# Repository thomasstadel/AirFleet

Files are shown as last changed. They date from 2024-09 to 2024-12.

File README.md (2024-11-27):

# AirFleet
Mobil kortlægning af luftkvalitet

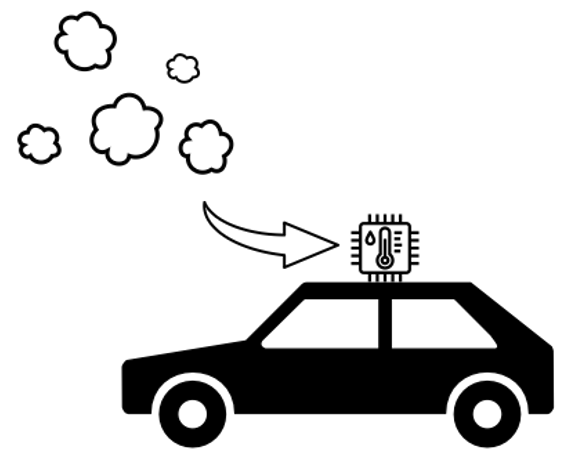
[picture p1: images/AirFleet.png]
AirFleet


## Formål
Formålet med dette projekt er at udvikle en IoT-løsning, der kan indsamle samples af luftkvalitet, herunder partikler, fugtighed, temperatur, CO2 baseret på GPS-lokation.

Enheden skal kunne installeres udvendigt (evt. ved luftindtag) på en bil.

Indsamlede data skal leveres til en webservice, hvor de skal gemmes i en database til efterfølgende analyse.

Der skal være et display på IoT-enheden, som giver mulighed for at informere føreren af bilen om luftkvalitet. 

Optimalt set vil IoT-enheden automatisk aktivere recirkulation i bilen ved lav luftkvalitet.

## Mappe-struktur

schematics/     Diagrammer og PCB layouts

display/        Kode relateret til display board

sensor/         Kode relateret til sensor board

stl/            STL-modeller af bokse

webserver/      Kode og database til webserver

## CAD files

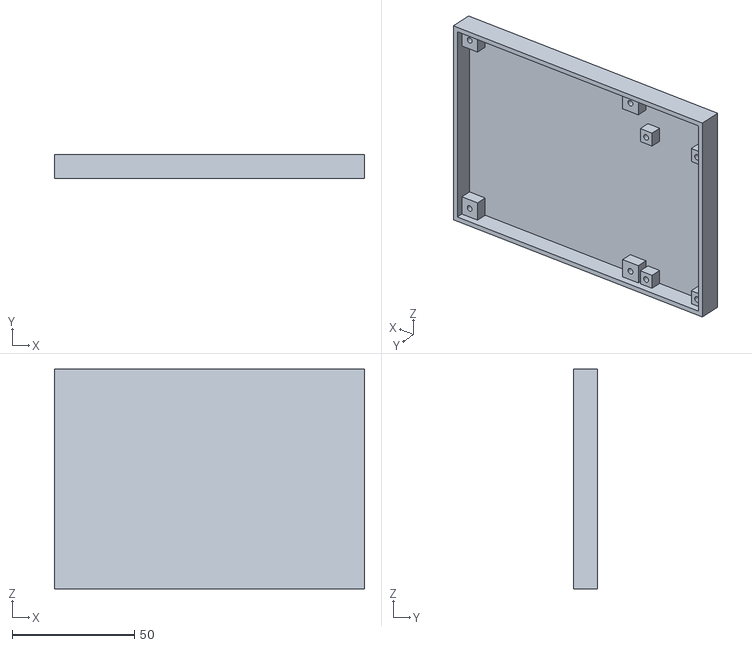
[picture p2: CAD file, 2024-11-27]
stl/sensor_bottom.stl
127.0 x 10.0 x 90.0

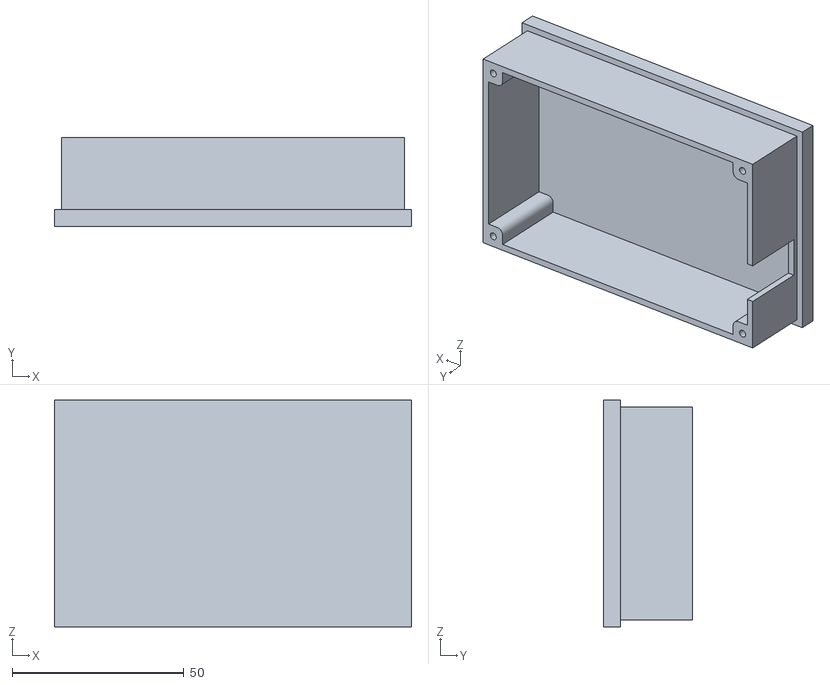
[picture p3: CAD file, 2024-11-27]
stl/display_back.stl
104.0 x 26.0 x 66.0

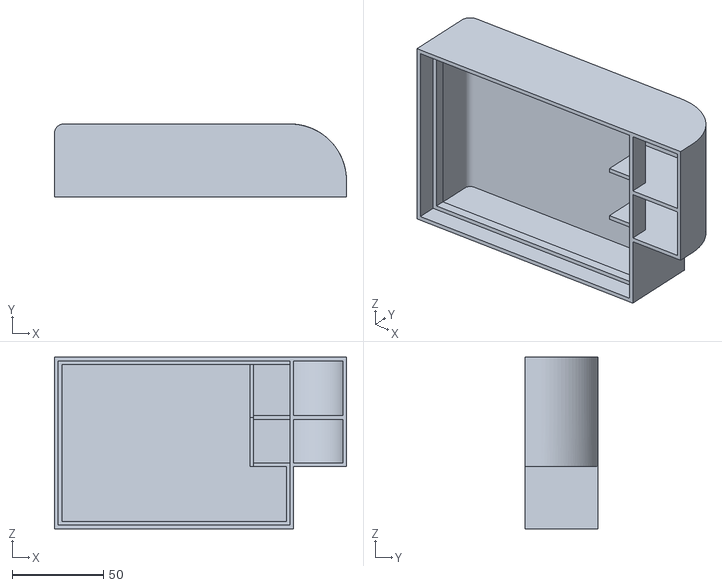
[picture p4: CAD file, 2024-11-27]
stl/sensor_top.stl
160.0 x 40.0 x 94.0

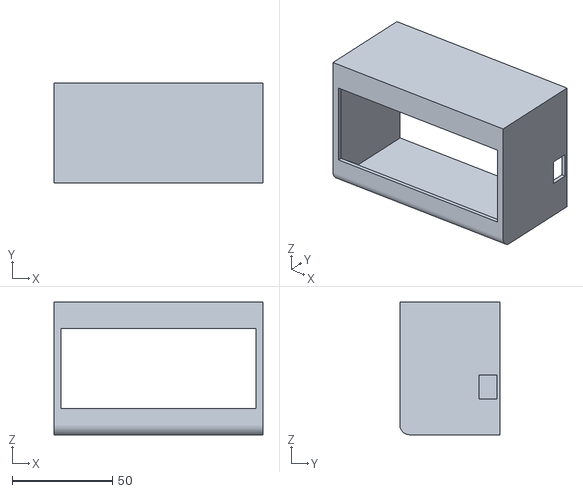
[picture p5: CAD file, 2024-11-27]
stl/display_front.stl
104.0 x 50.0 x 66.0

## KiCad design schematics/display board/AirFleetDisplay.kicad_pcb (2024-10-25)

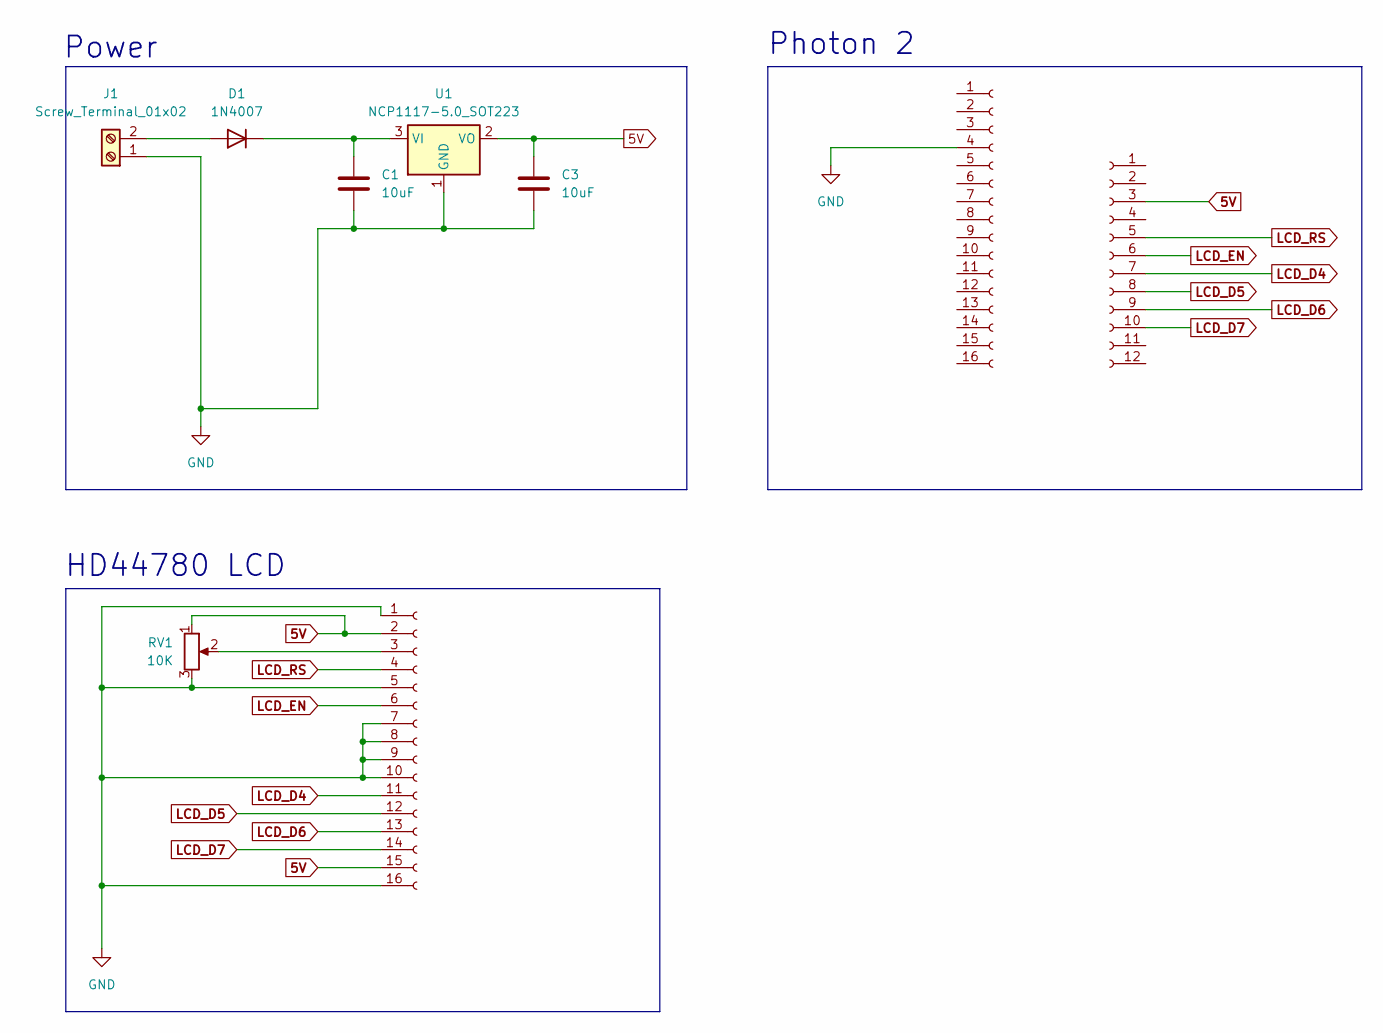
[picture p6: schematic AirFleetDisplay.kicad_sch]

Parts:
C1, C3: 10uF; C_1210_3225Metric_Pad1.33x2.70mm_HandSolder
D1: 1N4007; D_DO-15_P15.24mm_Horizontal
J1: Screw_Terminal_01x02; TerminalBlock_bornier-2_P5.08mm
J2, J4: Conn_01x16_Socket; PinSocket_1x16_P2.54mm_Vertical
J3: Conn_01x12_Socket; PinSocket_1x12_P2.54mm_Vertical
RV1: 10K; Potentiometer_Bourns_3386P_Vertical
U1: NCP1117-5.0_SOT223; SOT-223-3_TabPin2

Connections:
5V: C3.1, J3.3, J4.2, J4.15, RV1.1, U1.2 (VO)
GND: C1.2, C3.2, J1.1, J2.4, J4.1, J4.5, J4.7, J4.8, J4.9, J4.10, J4.16, RV1.3, U1.1 (GND)
LCD_D4: J3.7, J4.11
LCD_D5: J3.8, J4.12
LCD_D6: J3.9, J4.13
LCD_D7: J3.10, J4.14
LCD_EN: J3.6, J4.6
LCD_RS: J3.5, J4.4
unnamed: D1.2 (A), J1.2
unnamed: C1.1, D1.1 (K), U1.3 (VI)
unnamed: J4.3, RV1.2

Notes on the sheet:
HD44780 LCD
Photon 2
Power

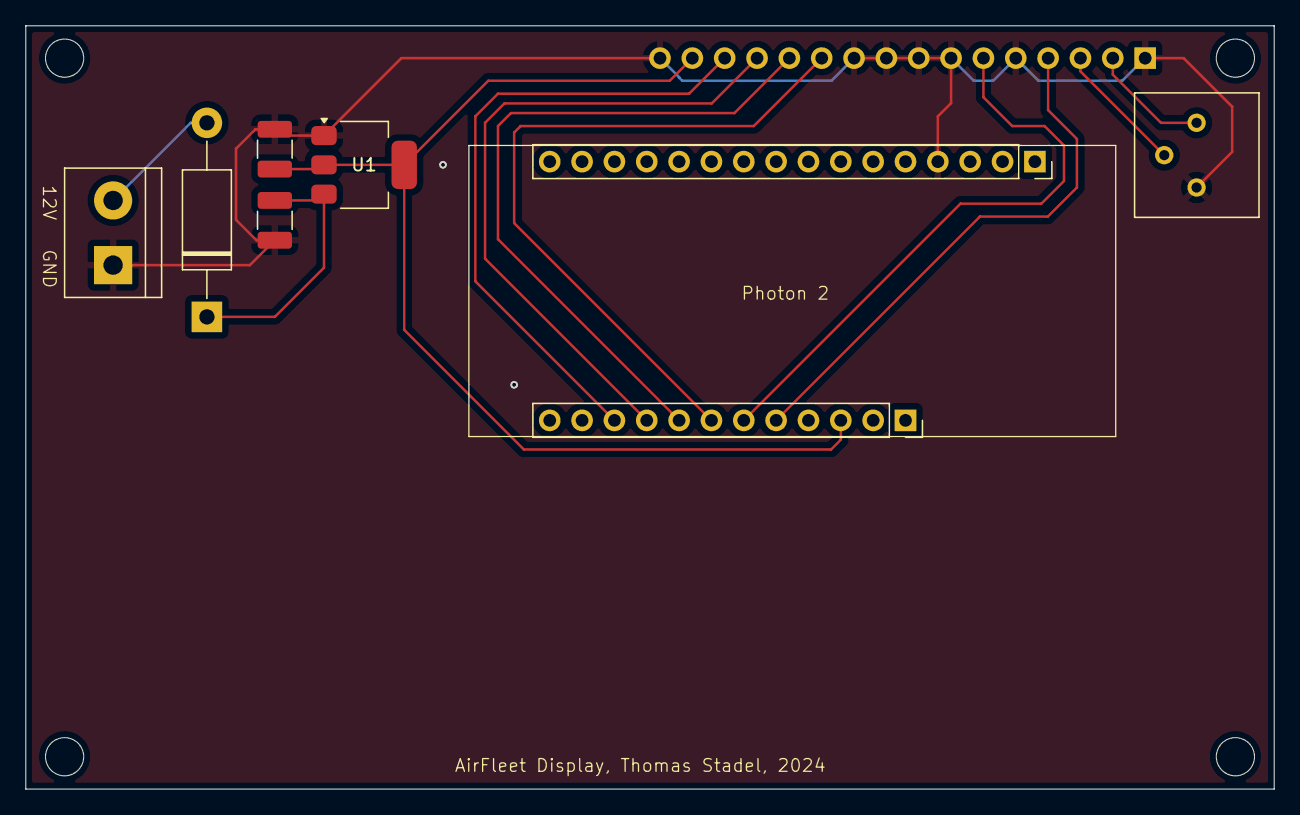
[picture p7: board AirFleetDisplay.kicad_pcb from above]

Board: 2 copper layers, 98.0 x 59.9 mm, 9 parts (1 on the bottom side), 11 nets.

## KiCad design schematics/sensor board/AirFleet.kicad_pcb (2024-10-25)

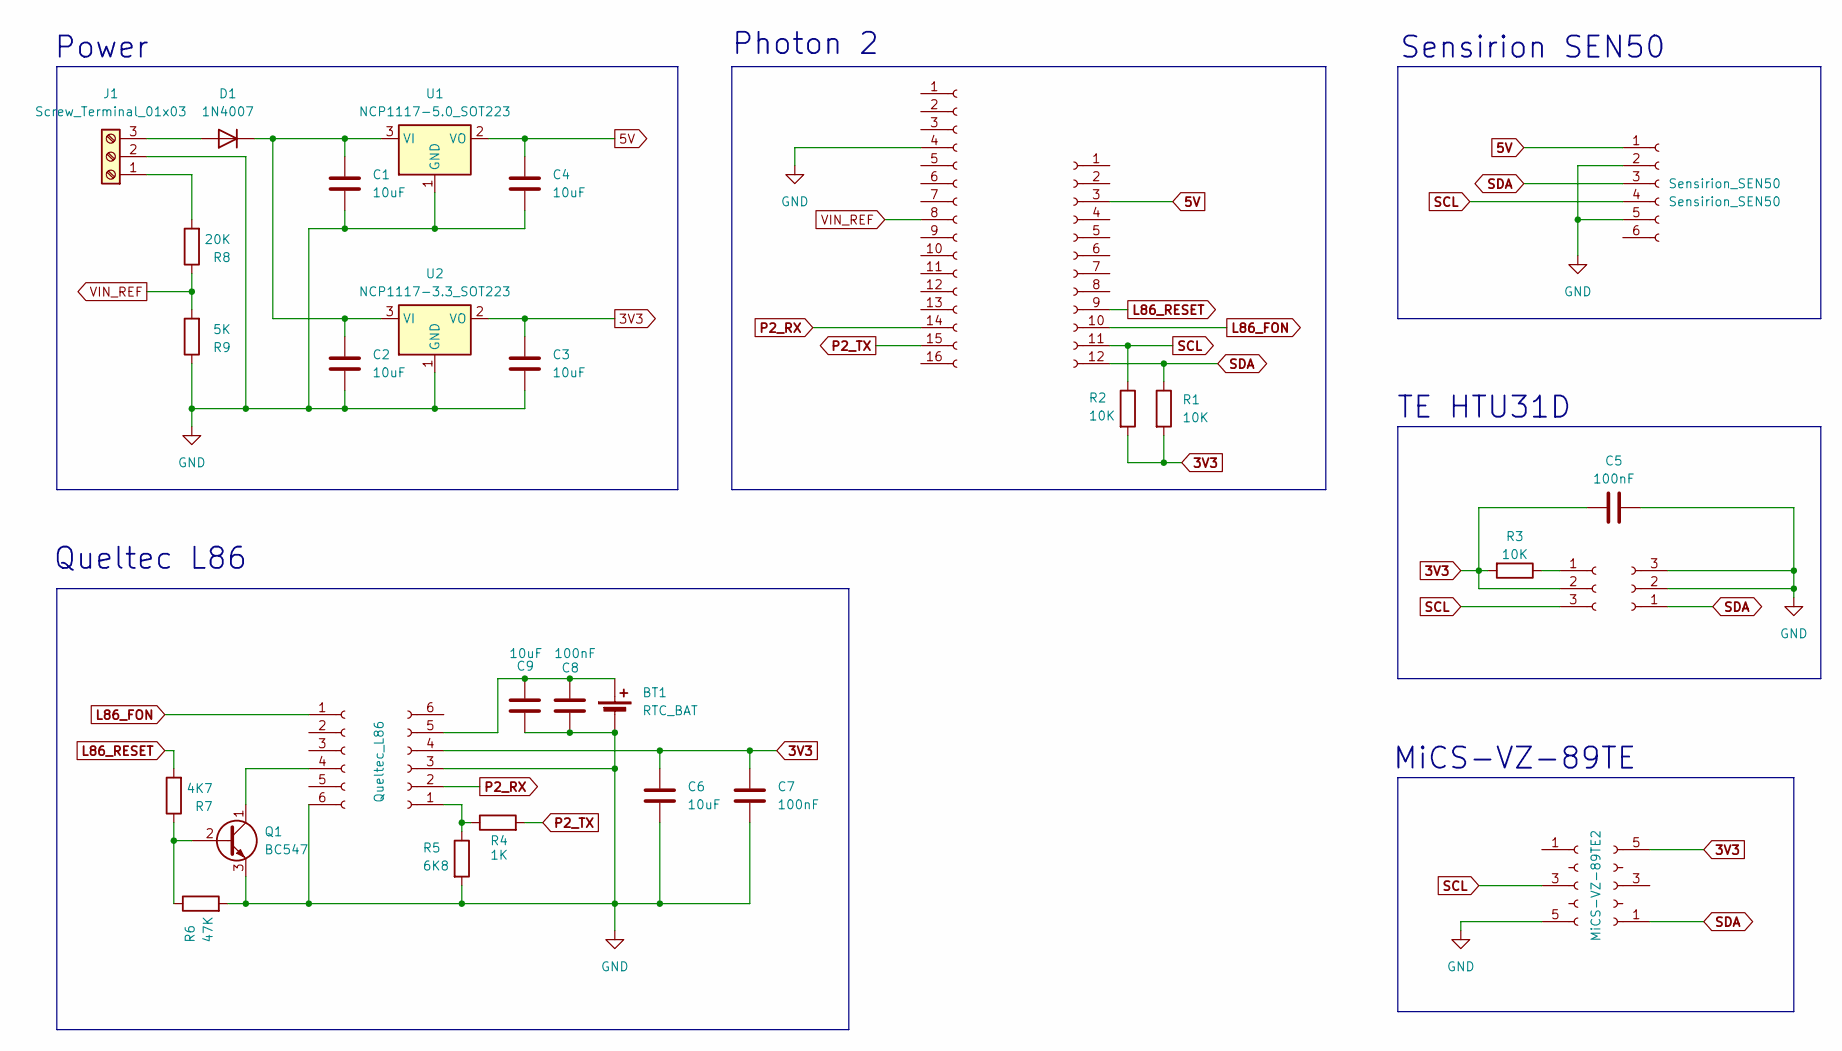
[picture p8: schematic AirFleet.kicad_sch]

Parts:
BT1: RTC_BAT; Battery_Panasonic_CR2032-HFN_Horizontal_CircularHoles
C1, C2, C3, C4, C6, C9: 10uF; C_1210_3225Metric_Pad1.33x2.70mm_HandSolder
C5, C7, C8: 100nF; C_1210_3225Metric_Pad1.33x2.70mm_HandSolder
D1: 1N4007; D_DO-15_P15.24mm_Horizontal
HTU31D1, HTU31D2: Conn_01x03_Socket; PinSocket_1x03_P2.54mm_Vertical
J1: Screw_Terminal_01x03; TerminalBlock_bornier-3_P5.08mm
J2: Conn_01x12_Socket; PinSocket_1x12_P2.54mm_Vertical
J3: Conn_01x16_Socket; PinSocket_1x16_P2.54mm_Vertical
J5: Conn_01x06_Socket; PinSocket_1x06_P2.54mm_Vertical
MiCS-VZ-89TE1, MiCS-VZ-89TE2: Conn_01x05_Socket; PinSocket_1x05_P2.54mm_Vertical
Q1: BC547; TO-92_Inline
Queltec_L86: Queltec_L86; PinSocket_1x06_P2.54mm_Vertical
R1, R2, R3: 10K; R_Axial_DIN0309_L9.0mm_D3.2mm_P12.70mm_Horizontal
R4: 1K; R_Axial_DIN0309_L9.0mm_D3.2mm_P12.70mm_Horizontal
R5: 6K8; R_Axial_DIN0309_L9.0mm_D3.2mm_P12.70mm_Horizontal
R6: 47K; R_Axial_DIN0309_L9.0mm_D3.2mm_P12.70mm_Horizontal
R7: 4K7; R_Axial_DIN0309_L9.0mm_D3.2mm_P12.70mm_Horizontal
R8: 20K; R_Axial_DIN0309_L9.0mm_D3.2mm_P12.70mm_Horizontal
R9: 5K; R_Axial_DIN0309_L9.0mm_D3.2mm_P12.70mm_Horizontal
Sensirion_SEN50: Sensirion_SEN50; PinSocket_1x06_P2.54mm_Vertical
U1: NCP1117-5.0_SOT223; SOT-223-3_TabPin2
U2: NCP1117-3.3_SOT223; SOT-223-3_TabPin2

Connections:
3V3: C3.1, C5.1, C6.1, C7.1, HTU31D1.2, MiCS-VZ-89TE2.5, Queltec_L86.4, R1.2, R2.2, R3.2, U2.2 (VO)
5V: C4.1, J2.3, Sensirion_SEN50.1, U1.2 (VO)
GND: BT1.2 (-), C1.2, C2.2, C3.2, C4.2, C5.2, C6.2, C7.2, C8.2, C9.2, HTU31D2.2, HTU31D2.3, J1.2, J3.4, J5.6, MiCS-VZ-89TE1.5, Q1.3 (E), Queltec_L86.3, R5.2, R6.2, R9.1, Sensirion_SEN50.2, Sensirion_SEN50.5, U1.1 (GND), U2.1 (GND)
L86_FON: J2.10, J5.1
L86_RESET: J2.9, R7.2
unnamed: BT1.1 (+), C8.1, C9.1, Queltec_L86.5
unnamed: D1.2 (A), J1.3
unnamed: C1.1, C2.1, D1.1 (K), U1.3 (VI), U2.3 (VI)
unnamed: HTU31D1.1, R3.1
unnamed: J1.1, R8.2
unnamed: J5.4, Q1.1 (C)
unnamed: Q1.2 (B), R6.1, R7.1
unnamed: Queltec_L86.1, R4.1, R5.1
P2_RX: J3.14, Queltec_L86.2
P2_TX: J3.15, R4.2
SCL: HTU31D1.3, J2.11, MiCS-VZ-89TE1.3, R2.1, Sensirion_SEN50.4
SDA: HTU31D2.1, J2.12, MiCS-VZ-89TE2.1, R1.1, Sensirion_SEN50.3
VIN_REF: J3.8, R8.1, R9.2

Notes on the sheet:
Sensirion SEN50
Queltec L86
TE HTU31D
MiCS-VZ-89TE
Photon 2
Power

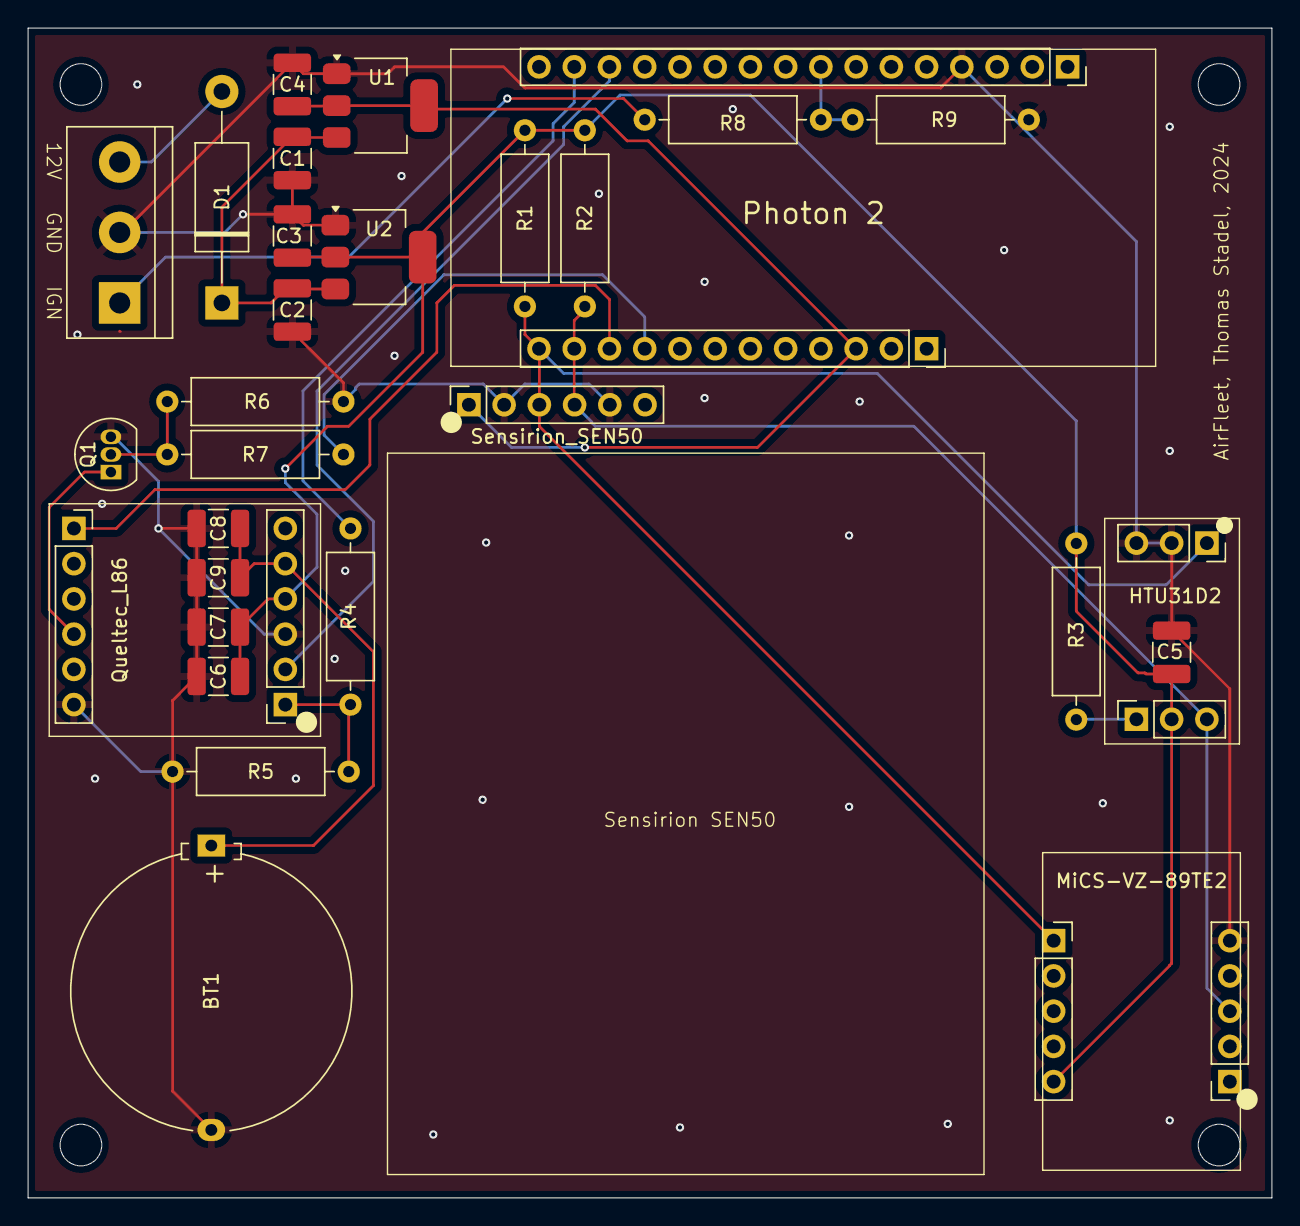
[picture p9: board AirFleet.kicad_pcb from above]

Board: 2 copper layers, 89.7 x 84.3 mm, 33 parts (0 on the bottom side), 18 nets.

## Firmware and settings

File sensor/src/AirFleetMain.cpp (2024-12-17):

/*
	@author:  Thomas Stadel
	@date:    2024-12-15
	@brief:   AirFleet mobile air quality sensor
*/

#include "Particle.h"

#include "BleLcd.h"
#include "Sen50.h"
#include "Htu31.h"
#include "Mics.h"
#include "L86.h"

#include "Settings.h"

// Run manual mode so we can control WiFi etc.
SYSTEM_MODE(MANUAL);

// Run the application and system concurrently in separate threads
SYSTEM_THREAD(ENABLED);

// Log handler (can be disabled in Settings.h)
#ifdef AIRFLEET_DEBUG
SerialLogHandler logHandler(LOG_LEVEL_INFO);
#endif

// BLE LCD
BleLcd lcd;

// Sensirion SEN50: particle sensor - has absolutely nothing to do with particle.io :-P
Sen50 sen50;

// HTU31 sensor: temperature + humidity
Htu31 htu31;

// MiCS sensor: VOC+CO2
Mics mics;

// L86 GPS module
L86 l86;

// Past averages [CO2, PM1, PM2.5, PM4, PM10]
float_t past_average[5] = {0., 0., 0., 0., 0.};

// States
enum State {
  INIT,
  IDLE,
  SAMPLE,
  PUBLISH,
  SLEEP,
  LEVELS
};
State state = INIT;

// Prototypes
String generate_scale(float_t val, float_t minval, float_t maxval, float_t prev, uint8_t width);
void airfleet_levels(const char *event, const char *data);
void disconnectCloud();
bool connectCloud();
void triggerSample();
bool isIgnitionOn();
float_t getBatteryV();

// Timer that triggers sample every X sec.
Timer sampleTimer(SAMPLE_INTERVAL_MS, triggerSample);

// Flag that forces LCD update
bool forceLcdUpdate = false;

void setup() {

#ifdef AIRFLEET_DEBUG
  // Wait for USB serial
  waitFor(Serial.isConnected, 15000);
  delay(1000);
#endif

  // Setup I2C
  Wire.setSpeed(I2C_SPEED);
  Wire.begin();

  // Setup sensors
  lcd = BleLcd();
  sen50 = Sen50();
  htu31 = Htu31();
  mics = Mics();
  l86 = L86();

  // Subscribe to air quality levels
  Particle.subscribe("hook-response/air-quality-request", airfleet_levels, MY_DEVICES);

  // Start sample timer
  sampleTimer.start();
}

void loop() {
  // Last millis, when data was published to cloud
  static system_tick_t publishTime = 0;

  // Last millis, when we got average PMs
  static system_tick_t levelsTime = 0;

  // Last known good samples
  static float_t log_pm[4] = { 0., 0., 0., 0. };
  static float_t log_th[2] = { 0., 0. };
  static uint16_t log_cv[2] = { 0, 0 };
  static String log_datetime = "0000-00-00 00:00:00";
  static float_t log_gps[4] = { 0., 0., 0., 0. };

  String datetime;
  float_t pm[4];
  uint8_t pm_result;
  float_t th[2];
  uint8_t th_result;
  uint16_t cv[2];
  uint8_t cv_result;
  float_t gps[4];
  uint8_t gps_result;

  // State machine
  switch (state) {
    case INIT:
      // Wake up everything
      sen50.on();
      lcd.on();
      htu31.on();
      mics.on();
      l86.on();

      // Take first sample after init
      state = SAMPLE;

      break;

    case IDLE:
      // Housekeeping for different modules

      lcd.loop();
      sen50.loop();
      htu31.loop();
      mics.loop();
      l86.loop();

      // Check if ignition is off
      if (!isIgnitionOn()) state = SLEEP;

      // Check if we need to publish to cloud
      else if (publishTime == 0 || publishTime + PUBLISH_INTERVAL_MS <= millis()) state = PUBLISH;

      break;

    case SAMPLE:
      // Get sample
      state = IDLE;

      // Get sample for all sensors
      gps_result = l86.getSample(gps, &datetime);
      pm_result = sen50.getSample(pm);
      th_result = htu31.getSample(th);
      cv_result = mics.getSample(cv);

      // Particles
      if (pm_result == 0 && (memcmp(pm, log_pm, sizeof(pm)) != 0 || forceLcdUpdate)) {
        // Find max PM part
        float_t maxpm = 0;
        for (size_t i = 0; i < sizeof(pm) / sizeof(pm[0]); i++) {
          if (pm[i] > maxpm) maxpm = pm[i];
        }

        // Update LCD
        lcd.print(0, 2, "PM  " + generate_scale(maxpm, PM_MIN, PM_MAX,
          (past_average[1] + past_average[2] + past_average[3] + past_average[4]) / 4., // Average PM
          16)); // + " " + String::format("%.1f", maxpm));

        memcpy(log_pm, pm, sizeof(log_pm));
      }

      // Temperature / humidity
      if (th_result == 0 && (memcmp(th, log_th, sizeof(th)) != 0 || forceLcdUpdate)) {
        // Show temp at top right in format: XXXC
        lcd.print(16, 0, String::format("%3.0fC", th[0]));

        // Show humidity right on second line: XX%RH
        lcd.print(8, 0, String::format("%2.0f%%RH", th[1]));

        memcpy(log_th, th, sizeof(log_th));
      }

      // CO2 / VOC
      if (cv_result == 0 && (memcmp(cv, log_cv, sizeof(cv)) != 0 || forceLcdUpdate)) {
        lcd.print(0, 1, "CO2 " + generate_scale((float_t)cv[1], CO2_MIN, CO2_MAX,
          past_average[0], 16)); // + " " + String(cv[1]));

        memcpy(log_cv, cv, sizeof(log_cv));
      }

      // GPS
      if (gps_result == 0) {
        // Show clock at top left 2024-11-11 11:11:11
        if (log_datetime.substring(11, 16) != datetime.substring(11, 16) || forceLcdUpdate) {
          lcd.print(0, 0, datetime.substring(11, 16));
        }
        log_datetime = datetime;

        if (memcmp(gps, log_gps, sizeof(gps)) != 0) {
          memcpy(log_gps, gps, sizeof(log_gps));
        }
      }
      else {
        // Show there's no GPS
        lcd.print(0, 0, "?GPS?");
      }

      // Show alerts
      if (log_pm[0] >= PM_MAX || log_pm[1] >= PM_MAX || log_pm[2] >= PM_MAX || log_pm[3] >= PM_MAX) {
        lcd.enableFlash(0, 3, "   PM NIVEAU H0J    ", 750);
      }
      else if (log_cv[1] >= CO2_MAX) {
        lcd.enableFlash(0, 3, "   CO2 NIVEAU H0J   ", 750);
      }
      else {
        lcd.disableFlash();
        lcd.print(9, 3, "OK");
      }

      // Check if we need to publish data
      if (log_gps[3] >= PUBLISH_INTERVAL_KM) state = PUBLISH;

      // Clear force update flag
      forceLcdUpdate = false;

#ifdef AIRFLEET_DEBUG
      Log.info("---------------");

      // Car battery
      Log.info("Battery voltage: %.1fV", getBatteryV());

      // Particles
      if (pm_result == 0) {
        Log.info("PM1: %.1f, PM2.5: %.1f, PM4: %.1f, PM10: %.1f", pm[0], pm[1], pm[2], pm[3]);
      }
      else {
        Log.error("Could not get particles in air");
      }

      // Temperature
      if (th_result == 0) {
        Log.info("Temperature: %.1f, humidity: %.1f", th[0], th[1]);
      }
      else {
        Log.error("Could not get temperature and humidity");
      }

      // CO2 / VOC
      if (cv_result == 0) {
        Log.info("VOC: %d, CO2: %d", cv[0], cv[1]);
      }
      else {
        Log.error("Could not get VOC/CO2");
      }

      // GPS
      if (gps_result == 0) {
        Log.info("GPS UTC time: %s", (const char*)datetime);
        Log.info("GPS Latitude: %f, Longitude: %f, Speed: %f, Distance: %f", gps[0], gps[1], gps[2], gps[3]);
      }
      else if (gps_result == 1) {
        Log.error("GPS looking for satelittes");
      }
      else {
        Log.error("No data from GPS");
      }

      Log.info("---------------");
#endif

      break;

    case PUBLISH:
      // Publish last sample to cloud

      state = IDLE;
      if (!connectCloud()) break;

#ifdef AIRFLEET_DEBUG
      Log.info("Publishing data to cloud");
#endif

      // Build JSON string
      char buf[255];
      snprintf(buf, sizeof(buf),
        "{"
        "\"pm1\":%.1f,\"pm25\":%.1f,\"pm4\":%.1f,\"pm10\":%.1f,"   // Particles
        "\"temp\":%.1f,\"humi\":%.1f,"                             // Temperature + humidity
        "\"voc\":%d,\"co2\":%d,"                                   // VOC + CO2
        "\"lat\":%.6f,\"lng\":%.6f,"                               // GPS lat, lng
        "\"time\":\"%s\""                                          // UTC time
        "}",
        log_pm[0], log_pm[1], log_pm[2], log_pm[3],
        log_th[0], log_th[1],
        log_cv[0], log_cv[1],
        log_gps[0], log_gps[1],
        (const char*)log_datetime
        );

      // Publish to cloud
      Particle.publish("airfleet_push", buf, PRIVATE);

      // Reset distance + publishtime, so publish will be triggered in X millisec./km
      l86.reset_distance();
      publishTime = millis();

      // Check if we need to update the past PM levels from cloud
      if (levelsTime == 0 || levelsTime + LEVELS_INTERVAL_MS <= millis()) {
        state = LEVELS;
      }
      else {
        // Disconnect WiFi
        disconnectCloud();
      }

      break;

    case LEVELS:
      // Update average particle levels
      state = IDLE;
      if (!connectCloud()) break;

#ifdef AIRFLEET_DEBUG
        Log.info("AIRFLEET_LEVELS Requesting...");
#endif

      // Request particle levels
      if (Particle.publish("air-quality-request", "", PRIVATE)) levelsTime = millis();

      break;

    case SLEEP:
      // Go to sleep mode

#ifdef AIRFLEET_DEBUG
      Log.info("=== GOING TO SLEEP  ===");
#endif

      // Update LCD
      lcd.disableFlash();
      lcd.clear();
      lcd.print(0, 1, "    TAENDING FRA");

      // Put everything asleep
      sen50.off();
      lcd.off();
      htu31.off();
      mics.off();
      l86.off();

      // Put Photon 2 to sleep, and wakeup every X sec to check for ignition
      SystemSleepConfiguration config;
      config.mode(SystemSleepMode::ULTRA_LOW_POWER).duration(IGNITION_CHECK_INTERVAL);
      while (!isIgnitionOn()) System.sleep(config);

#ifdef AIRFLEET_DEBUG
      Log.info("=== WOKE UP ===");
#endif

      state = INIT;

      break;
  }
}

// Timer for triggering sampling
void triggerSample() {
  if (state != SLEEP) state = SAMPLE;
}

// Start and check connection to Particle cloud
bool connectCloud() {

    // Check WiFi
    if (WiFi.isOff()) {

#ifdef AIRFLEET_DEBUG
      Log.info("CLOUD connecting");
#endif

      WiFi.on();
      WiFi.connect();
      Particle.connect();
      return false;
    }
    if (!WiFi.ready()) return false;

    // Check Particle cloud
    if (!Particle.connected()) return false;

    return true;
}

// End connection to Particle cloud
void disconnectCloud() {
  if (WiFi.isOff()) return;

#ifdef AIRFLEET_DEBUG
  Log.info("CLOUD disconnecting");
#endif

  Particle.disconnect();
  WiFi.off();
}

// Callback when we get past average levels
void airfleet_levels(const char *event, const char *data) {
#ifdef AIRFLEET_DEBUG
  Log.info("AIRFLEET_LEVELS CALLBACK event: %s, data: %s", event, data);
#endif

  // Parse JSON
  JSONValue jsondata = JSONValue::parseCopy(data);

  // Iterate through elements in JSON
  JSONObjectIterator iter(jsondata);
  while (iter.next()) {

#ifdef AIRFLEET_DEBUG    
    Log.info("JSON %s: %s", (const char *)iter.name(), (const char *)iter.value().toString());
#endif

    if (iter.name() == "co2") {
      past_average[0] = (float_t)iter.value().toDouble();
    }
    else if (iter.name() == "pm1") {
      past_average[1] = (float_t)iter.value().toDouble();
    }
    else if (iter.name() == "pm25") {
      past_average[2] = (float_t)iter.value().toDouble();
    }
    else if (iter.name() == "pm4") {
      past_average[3] = (float_t)iter.value().toDouble();
    }
    else if (iter.name() == "pm10") {
      past_average[4] = (float_t)iter.value().toDouble();
    }
  }

  disconnectCloud();

  forceLcdUpdate = true;
}

// Function generating a scale, e.g.:
// [---    |    ]
String generate_scale(float_t val, float_t minval, float_t maxval, float_t prev, uint8_t width) {
  String scale = "[";
  int8_t val_i = (int8_t)((val - minval) / (maxval - minval) * (float_t)(width - 2));
  if (val_i < 0) val_i = 0;
  if (val_i > width - 3) val_i = width - 3;
  int8_t prev_i = (int8_t)((prev - minval) / (maxval - minval) * (float_t)(width - 2));
  if (prev_i < 0) prev_i = 0;
  if (prev_i > width - 3) prev_i = width - 3;
  for (uint8_t i = 0; i < width - 2; i++) {
    if (val_i >= i && prev_i == i) {
      scale.concat("+");
    }
    else if (val_i >= i) {
      scale.concat("-");
    }
    else if (prev_i == i) {
      scale.concat("|");
    }
    else {
      scale.concat(" ");
    }
  }
  scale.concat("]");
  return scale;
}

bool isIgnitionOn() {
  return getBatteryV() >= IGNITION_ON_V;
}

float_t getBatteryV() {
  return analogRead(VIN_REF_PIN) * VIN_REF_FACTOR;
}

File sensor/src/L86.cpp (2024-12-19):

/*
	@author:  Thomas Stadel
	@date:    2024-11-25
	@brief:   Driver for Queltec L86 GPS module
*/

#include "L86.h"

L86::L86() {
	// Setup GPIOs
	pinMode(L86_RESET_PIN, OUTPUT);
	pinMode(L86_FORCEON_PIN, OUTPUT);

	digitalWrite(L86_RESET_PIN, LOW);
	digitalWrite(L86_FORCEON_PIN, HIGH);
	delay(50);
	
	// Reset module to make sure we're in correct state
	reset();

	// Open UART
	L86_SERIAL.begin(9600);
	waitFor(L86_SERIAL.isEnabled, 15000);
	delay(1000);

	String str;
	if (L86_BAUDRATE != 9600) {
		// Empty read buffer
		while (L86_SERIAL.available()) L86_SERIAL.read();

		// Set baudrate of GPS module
		str = "$PMTK251,";
		str.concat(L86_BAUDRATE);
		str.concat("*");
		str.concat(calcCRC(str));
		str.concat("\r\n");
		L86_SERIAL.print(str);

		// Change baudrate of serial
		L86_SERIAL.flush();
		L86_SERIAL.end();

		L86_SERIAL.begin(L86_BAUDRATE);
		waitFor(L86_SERIAL.isEnabled, 15000);
		delay(1000);
	}

	// Empty read buffer
	while (L86_SERIAL.available()) L86_SERIAL.read();

	// Set fixpoint interval
	str = "$PMTK220,";
	str.concat(SAMPLE_INTERVAL_MS);
	str.concat("*");
	str.concat(calcCRC(str));
	str.concat("\r\n");
	L86_SERIAL.print(str);
#ifdef AIRFLEET_DEBUG
	Log.info("GPS setting interval: %s", (const char*)str);
#endif

	// Set defaults
	gps_valid = -1;
	gps_latitude = 0.;
	gps_longitude = 0.;
	gps_prev_latitude = 0.;
	gps_prev_longitude = 0.;
	gps_speed = 0.;
	gps_distance = 0.;
	gps_millis = 0;
	gps_datetime = "0000-00-00 00:00:00";	
}

void L86::reset() {
	/*
		Reset module according to datasheet.
		Ref: https://docs.rs-online.com/1fe5/0900766b8147dbfb.pdf

		Note, that the logic is inverted, because a transistor is
		used for pulling down the reset pin, according to schematics.
		Ref: https://github.com/thomasstadel/AirFleet/blob/main/schematics/sensor%20board/AirFleet.kicad_sch
	*/
	digitalWrite(L86_FORCEON_PIN, LOW);
	digitalWrite(L86_RESET_PIN, LOW);
	delay(5); // > 2ms
	digitalWrite(L86_RESET_PIN, HIGH);
	delay(15); // > 10ms
	digitalWrite(L86_RESET_PIN, LOW);
	delay(15); // Make sure module has restarted
}

void L86::loop() {
	// Empty serial buffer
	while (L86_SERIAL.available()) {
		// Read single character
		char c = (char)L86_SERIAL.read();

		// Start new command
		if (c == '$') {
			readBuffer = c;

			if (gps_valid == -1) gps_valid = 1;
		}
		
		// Check for newlines
		else if (c == '\r') {
			String str = trim(readBuffer);
			readBuffer = "";

	#ifdef AIRFLEET_DEBUG
			Log.info("GPS data: %s", (const char*)str);
	#endif

			// Check if this is GPS position data
			// Expected format: $GNRMC,105117.000,A,5626.2207,N,00922.2751,E,0.00,2.02,251124,,,A,V*00
			if (str.startsWith("$GNRMC,") && str.indexOf("*") > -1) {

				// CRC check
				if (str.substring(str.length() - 2) == calcCRC(str.substring(0, str.length() - 2))) {
					// CRC OK

	#ifdef AIRFLEET_DEBUG
					Log.info("GPS data CRC OK");
	#endif

					// Build datetime string
					String date_part = getPart(str, 9);
					String time_part = getPart(str, 1);
					if (date_part.length() == 6 && time_part.length() == 10) {
						// Seems ok
						gps_datetime = "20"; // TODO: In year 2100, please change this to 21,
											// and increment this todo. I wont be there to
											// thank you, so thank you in advance!

						// Date part
						gps_datetime.concat(date_part.substring(4, 6)); // Year
						gps_datetime.concat("-");
						gps_datetime.concat(date_part.substring(2, 4)); // Month
						gps_datetime.concat("-");
						gps_datetime.concat(date_part.substring(0, 2)); // Date
						gps_datetime.concat(" ");

						// Time part
						gps_datetime.concat(time_part.substring(0, 2)); // Hour
						gps_datetime.concat(":");
						gps_datetime.concat(time_part.substring(2, 4)); // Minute
						gps_datetime.concat(":");
						gps_datetime.concat(time_part.substring(4, 6)); // Second
					}

					// Check if data is valid
					if (getPart(str, 2) == "A") {
						// Valid data

						// GPS position
						gps_latitude = calcDecimalDegrees(getPart(str, 3));
						if (getPart(str, 4) == "S") gps_latitude *= -1;
						gps_longitude = calcDecimalDegrees(getPart(str, 5));
						if (getPart(str, 6) == "W") gps_longitude *= -1;

						// Speed - knots to km/t. 1 knot = 1.852 km/t
						// Ref: https://en.wikipedia.org/wiki/Knot_(unit)
	#ifdef L86_DEBUG_SPEED	
						gps_speed = L86_DEBUG_SPEED;
	#else
						gps_speed = getPart(str, 7).toFloat() / 1.852;
	#endif

						// Calculate distance since last sample
	#ifdef L86_DISTANCE_BY_SPEED
						// Calculate distance using time delta and speed
						if (gps_millis > 0) {
							unsigned long time_delta = millis() - gps_millis;
							gps_distance += gps_speed / 3600000. * time_delta;
						}
	#else
		#ifdef L86_DISTANCE_BY_HAVERSINE
						// Calculate distance using Haversine formula
						if (gps_prev_latitude != 0. && gps_prev_longitude != 0.) {

							/*
								BEGIN Haversine implementation
								This code originates from:
								https://www.geeksforgeeks.org/haversine-formula-to-find-distance-between-two-points-on-a-sphere/
							*/

							// distance between latitudes and longitudes
							double_t dLat = (gps_prev_latitude - gps_latitude) * M_PI / 180.0;
							double_t dLon = (gps_prev_longitude - gps_longitude) * M_PI / 180.0;
					
							// convert to radians
							double_t lat1 = (gps_prev_latitude) * M_PI / 180.0;
							double_t lat2 = (gps_latitude) * M_PI / 180.0;
					
							// apply formulae
							double_t a = pow(sin(dLat / 2), 2) + 
									pow(sin(dLon / 2), 2) * 
									cos(lat1) * cos(lat2);
							double_t rad = 6371;
							double_t c = 2 * asin(sqrt(a));
							gps_distance += (float_t)(rad * c);

							/*
								END Haversine implementation
							*/
						}
		#endif
	#endif

						gps_prev_latitude = gps_latitude;
						gps_prev_longitude = gps_longitude;
						gps_millis = millis();
						gps_valid = 0;
					}
					else {
						// No valid GPS position
						gps_latitude = 0.;
						gps_longitude = 0.;
						gps_speed = 0.;
						gps_valid = 1;
					}
				}
				else {
					// CRC error
	#ifdef AIRFLEET_DEBUG				
					Log.error("CRC error reading from GPS-module. Got CRC: %s, calculated CRC: %s",
						(const char*)str.substring(str.length() - 2),
						(const char*)calcCRC(str.substring(0, str.length() - 2)));
	#endif
				}
			}
		}

		// Append to buffer
		else  {
			readBuffer.concat(c);
		}
	}
}

void L86::on() {
	// Empty readbuffer
	readBuffer = "";

	// Make sure serial is enabled
	if (!L86_SERIAL.isEnabled()) {
		L86_SERIAL.begin(L86_BAUDRATE);
		waitFor(L86_SERIAL.isEnabled, 5000);
		delay(1000);
	}

	// Force the GPS module on
	digitalWrite(L86_FORCEON_PIN, HIGH);
	delay(50);
}

void L86::off() {
	// Send GPS module to backup mode
	digitalWrite(L86_FORCEON_PIN, LOW);
	delay(10);
	L86_SERIAL.println("$PMTK225,4*2F");
	L86_SERIAL.flush();
	delay(10);
	L86_SERIAL.end();
}

void L86::reset_distance() {
	gps_distance = 0.;
}
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

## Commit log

2024-10-25 Added schematics for main and display board
    [AirFleet.kicad_pcb, AirFleet.kicad_sch, AirFleetDisplay.kicad_pcb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]
2024-10-25 Opdateret PCB til display
    [AirFleetDisplay.kicad_pcb]
2024-11-22 Tilføjet driver til BLE enabled LCD og Sensirion sensor
2024-11-24 Tilføjet driver til HTU31, L86, MiCS
2024-11-27 Opdateret sensor, webserver, 3D print filer
    [display_back.stl, display_front.stl, sensor_bottom.stl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]
